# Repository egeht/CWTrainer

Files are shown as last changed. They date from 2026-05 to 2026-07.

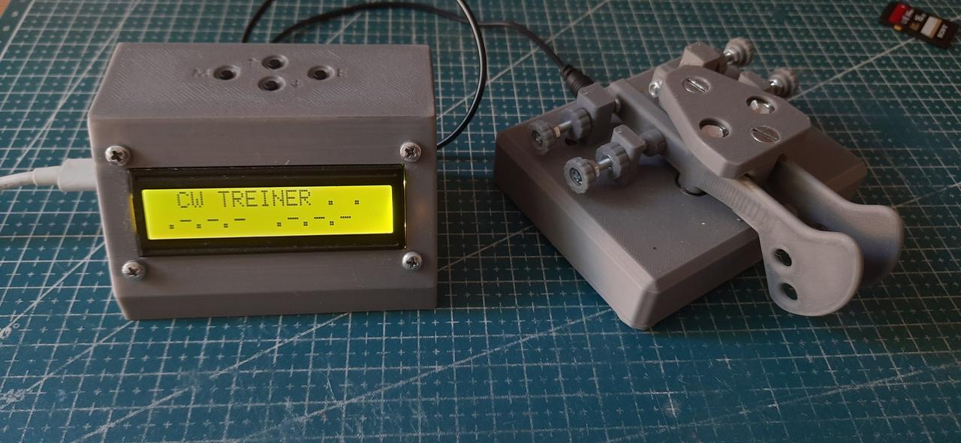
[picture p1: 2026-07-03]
docs/CWTrainer4.jpg

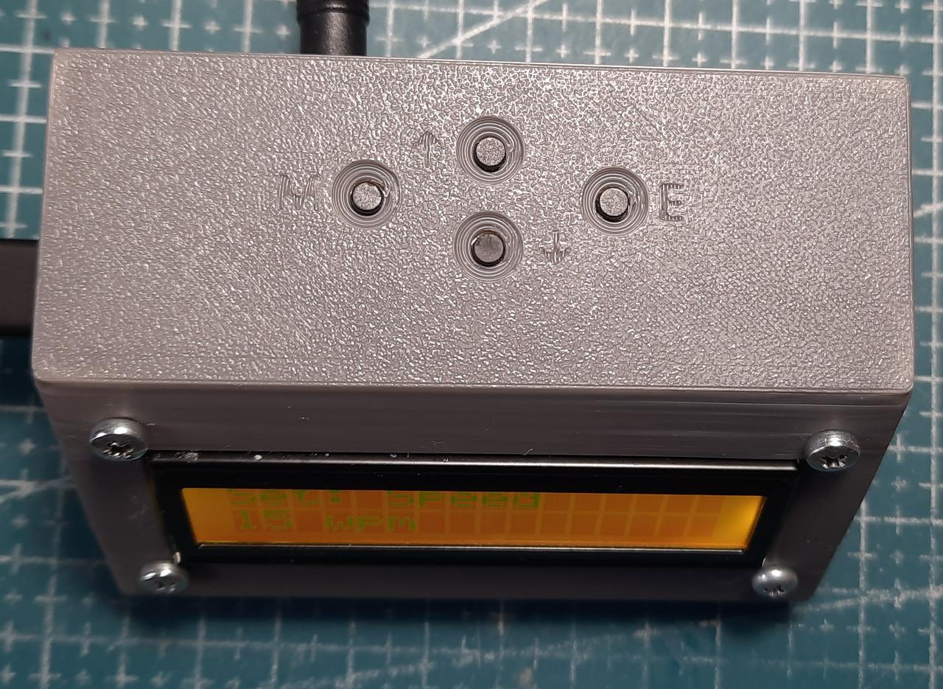
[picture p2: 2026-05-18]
docs/CWTrainer2.jpg

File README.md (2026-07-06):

# CWTrainer

Arduino nano CW electronic key/trainer

I needed an electronic CW key to learn Morse code (for practicing transmission). I came across an old key project from a radio amateur with the call sign PA3HCM (https://www.pa3hcm.nl/?p=1010). I used it as a basis. In the process, I modified the program so much that nothing remained of the original. :-)

The circuit diagram is almost unchanged (there's not much to change), I just replaced the board with an Arduino nano. To output sound to a speaker or headphones, I added a PAM8403 amplifier and a volume control. Just in case, I connected it to a transceiver, but I don't know why. If desired, you can plug a 3.5mm jack with an LED soldered onto it and see the light signals. I added four buttons to control the key setup menu. I also designed the enclosure.

What it can do:
- Works in iambic modes A and B.
- Works with a classic straight key.
When working with an iambic key, it displays the transmitted dots/dashes (on the bottom line) and the transmitted character (on the top line). This allows you to monitor the transmission.

The following parameters are configurable and stored in non-volatile memory:
- speed in WPM
- dash duration
- pause duration between signals
- pause duration between characters
- pause duration between words
All durations are entered in dot durations.

A printed circuit board (PCB) with a connector for the Arduino and a board with an audio amplifier and a volume control resistor is mounted on the bottom of the case (bottom step). The LCD1602 screen, a PCB with buttons, three connectors, and a speaker are mounted on the top of the case (top step).

I won't give any details on the components and layout, as everyone will have to use what they have on hand for this project.

This isn't a full-fledged simulator; it doesn't give you any tasks. And it doesn't check whether you've typed the right thing. It only shows what you've entered. But that's all I needed. :-)

You can see an example of it here - https://youtube.com/shorts/XV8_UpXhKHY?feature=share

# CWTrainer

Arduino nano CW электронный ключ/тренажер
 
Мне понадобился электронный CW ключ для изучения азбуки Морзе (для тренировки передачи). На глаза попался старый проект ключа от радиолюбителя с позывным PA3HCM (https://www.pa3hcm.nl/?p=1010). Взял его за основу. в процессе доработал программу так, что от оригинала ничего не осталось. :-)

Схема почти не поменялась (там и менять-то особенно не чего), только заменил платку на Arduino nano. Что бы можно было выводить звук на динамик или наушники добавил УНЧ на PAM8403 и регулятор громкости. На всякий случай сделал вывод на трансивер, не знаю зачем. При желании можно в него воткнуть джек 3.5 с припаянным светодиодом и видеть световые сигналы. Добавил четыре кнопки для управления меню настройки ключа. Нарисовал корпус.

Что умеет:
- Работает в ямбических режимах А и Б.
- Работает с классическим прямым ключом.
При работе с ямбическим ключом выводит на экран переданные точки/тире (в нижней строке) и переданный знак (в верхней строке). Таким образом можно контролировать передачу.

Настраивается и сохраняется в энергонезависимой памяти:
- скорость в WPM
- длительность тире
- длительность паузы между сигналами
- длительность паузы между символами
- длительность паузы между словами
Все длительности вводятся в длительностях точки.

На нижней части корпуса (bottom.step) крепится печатная (монтажная) плата с разъемом для Ардуино и платка с УНЧ и резистором регулятора громкости. На верхней части корпуса (top.step) экран LCD1602, печатная платка с кнопками, три разъема и динамик.

Не даю подробности комплектации и компоновки, потому что каждый будет делать исходя из того что у него есть под рукой для этого проекта.

Это не полноценный тренажер, он не дает вам ни каких заданий. И ни как не проверяет то ли вы набрали. Он только показывает что вы передали. Но мне только это и нужно было. :-)

Пример работы можно посмотреть здесь - https://youtube.com/shorts/XV8_UpXhKHY?feature=share

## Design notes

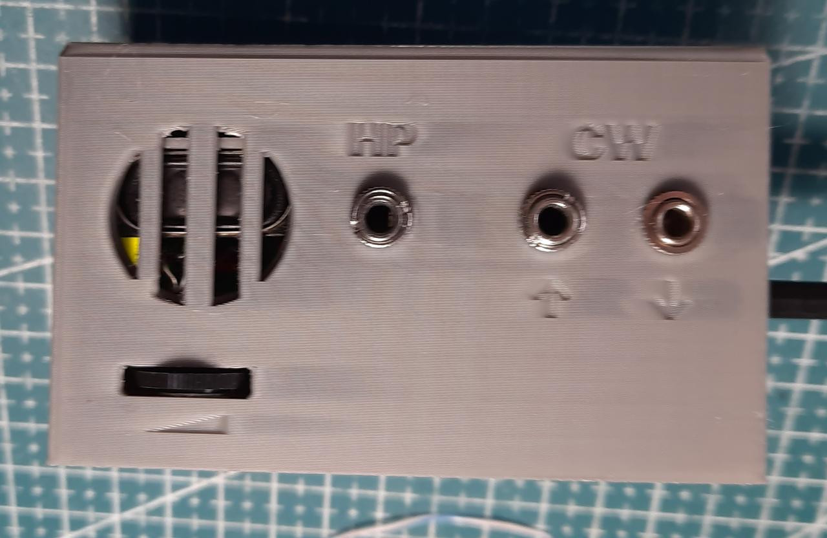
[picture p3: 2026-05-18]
docs/CWTrainer1.jpg

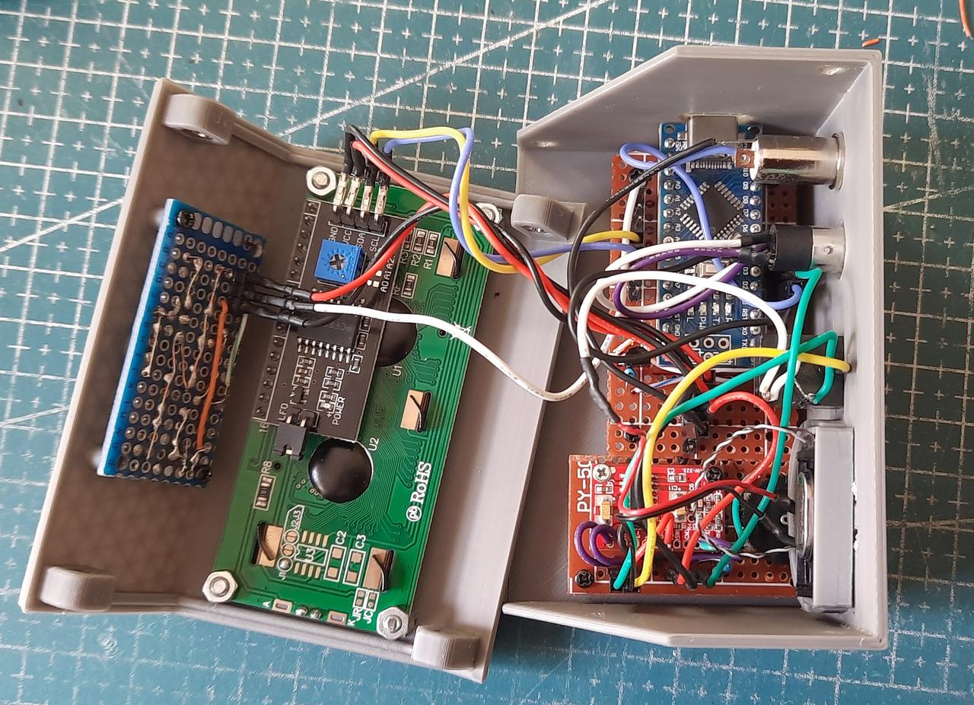
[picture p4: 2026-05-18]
docs/CWTrainer3.jpg

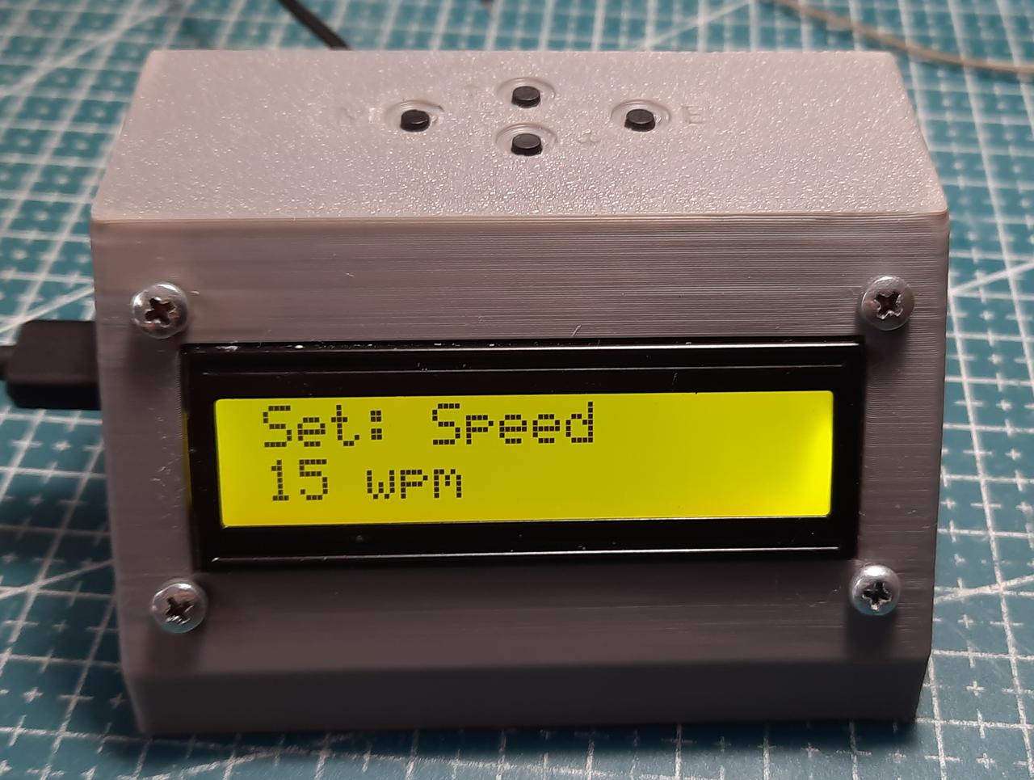
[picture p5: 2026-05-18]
docs/CWTrainer.jpg

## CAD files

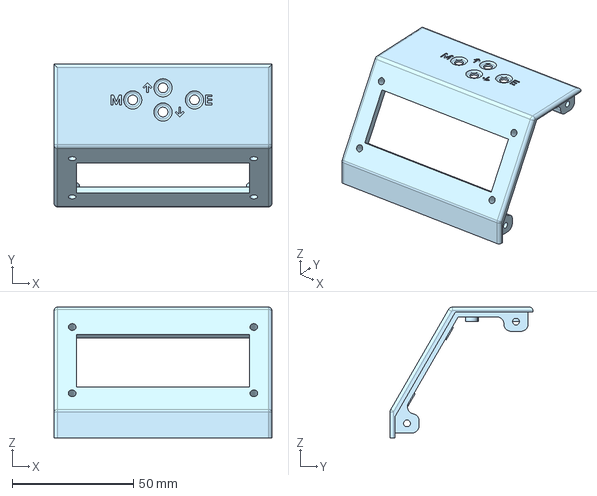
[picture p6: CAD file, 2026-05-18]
3d_models/top.step
90.0 x 59.0 x 54.0 mm

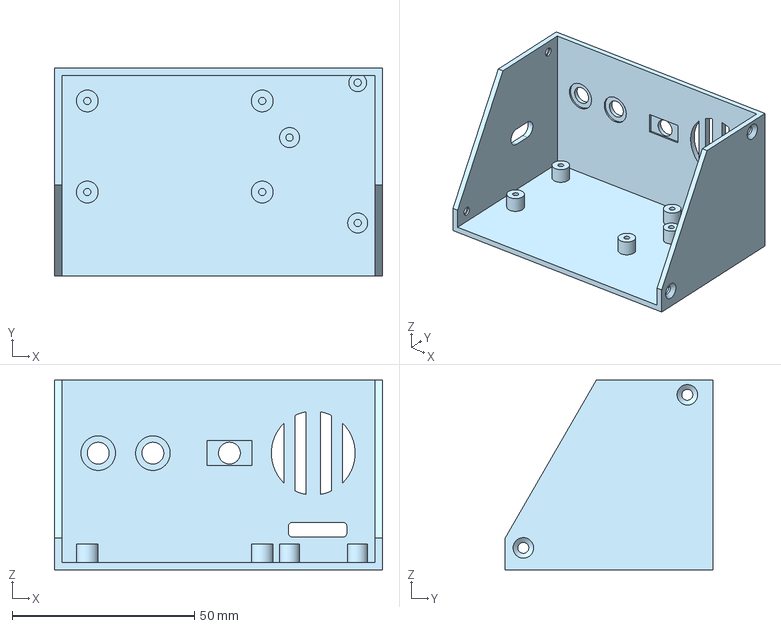
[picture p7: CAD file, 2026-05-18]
3d_models/bottom.step
90.0 x 57.0 x 52.0 mm

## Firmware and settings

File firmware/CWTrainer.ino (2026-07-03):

// CWTrainer
//
// by egeht exRA9MLF
// ver. 202600703
#define VER "1.00"
// 0.8 - замена обработки дребезга на бибоиотеку\
// 0.81 - реализация ямбик режима, вынов всего в функции
// 0.83 - как-то заработала, но похоже есть ошибки связанные с временем нажатия клавиш
// 0,84 - оставляем один опрос клавиш на цикл, реагируем только на устойчивые состояния, а не на события.
// 0.85 - замедлил опрос до один в 1 миллисекунду, почистил от старья. Работает в режиме ямбик А
// 0,86 - реализация режимов моде А и моде Б
// 0.87 - реализация режимов моде А и моде Б (отлажен)
// 0.88 - добавлен приямой ключ
// 0.89 - обработка нажатия кнопок управления меню
// 0.90 - сохранение настроек в eprom
// 0.91 - настройка программы
// 0.92 - RC1
// 0.93 - RC2 добавлне вывод на трнанссивер, этуляция обычного ключа (ключ нажат/не неажат)
// 0.94 - RC2
// 0,95 - изменил код ошибки и поменял местами точку и запятую
// 1.00 - изменил настройку промежутков междц словами (до 14) и шаг изменения на 0,5 RELISE

#include <SimpleButton.h>  // подавление дребезга
#include <LiquidCrystal_I2C.h>
#include <EEPROM.h>

LiquidCrystal_I2C lcd(0x27, 16, 2);  // адрес, столбцов, строк

bool IfDebug = false;  // true - включить отладку
// bool IfDebug = true;  // true - включить отладку
// bool IfDebug1 = false;
// bool IfDebug1 = true;

// Pin configuration
#define P_DOT 4       // D4 Connects to the dot lever of the paddle
#define P_DASH 5      // D5 Connects to the dash lever of the paddle
#define P_AUDIO 3     // D3 Speaker output
#define P_LCD_SDA A4  // LCD 1602 SDA
#define P_LCD_SCL A5  // LCD 1602 SCL
#define P_BTN A0      // Buttons
#define P_CW 6        // D output for transsiver

// microsecs in minute
#define US_PER_MIN 60000000

// 50 dot-long intervals in one "PARIS".
#define DOTS_PER_WORD 50

// логическое состояние ключа
#define DOT 1
#define DASH 2
#define NONE 3

// Режимы работы ямбик-ключа
#define IAMBIC_MODE_A 0  // классический режим A
#define IAMBIC_MODE_B 1  // режим B (с лишним элементом)
#define STRAIGHT_MODE 2  // вертикальный ключ

uint8_t iambicMode = IAMBIC_MODE_A;  // по умолчанию режим A
uint8_t pendingElement = NONE;       // для режима B: отложенный элемент после отпускания

float duration_dash = 3;        // длительность тире (в точках)
float pause_sign = 1;           // длительность паузы между сигналами (точка/тире)
float pause_letter = 3.0;       // длительность паузы между буквами
float pause_word = 7.0;         // длительность паузы между словами
uint16_t tone_frequency = 700;  // частота тона в герцах
uint8_t speed = 15;             // скорость передачи в словах в минуту

// длительности в единицах времени (ms - миллисекуды, us - микросекунды)
uint32_t stateTimerUs, duration_dot_us, duration_dash_us, pause_sign_us, pause_letter_us, pause_word_us;

uint8_t state;        // состояние автомата// состояния конечного автомата
#define state_Idle 1  // ничего не нажато, ждём paddle
#define state_Dot 3   // ключуем точка
#define state_Dash 4  // ключуем тире
#define state_Gap 5   // выдерживаем паузу после элемента

// уровень сигнала на пинах ключа
SimpleButton btnDot;   // true если точка нажата с подавлением дребезга
SimpleButton btnDash;  // true если тире нажата с подавлением дребезга

String morseLine = "";        // буфер точек/тире для показа на экране
String decodedLine = "";      // буфер расшифрованных букв для показа на экране
String morseBuffer = "";      // буфер одной буквы для рассшифровки
uint32_t silenceTimerUs = 0;  // таймер тишины с последнего элемента
bool decodingActive = false;  // флаг "идёт набор буквы"
bool wordSpaceAdded = false;  // флаг что слово закончено и пробел выведен

bool dotMemory = false;         // нажата точка
bool dashMemory = false;        // нажато тире
uint8_t currentElement = NONE;  // что сейчас звучит или только что звучало: DOT/DASH/NONE

bool dotIsPressed = false;  // устойчивое состояние: true - нажата, false - отпущена
bool dashIsPressed = false;
bool isToneOn;  // в режиме прямого ключа сигнал звучит

uint16_t BtnValue = 0;  // Состояние покоя кнопок

// Переменные меню
#define MENU_TIMEOUT 30000  // 30 секунд таймаут
#define MENU_OFF 0          // обычная работа ключа
#define MENU_SELECT 1       // выбор параметра (UP/DOWN перебираем параметры)
#define MENU_EDIT 2         // редактирование выбранного параметра (UP/DOWN меняем значение)
uint8_t menuState = 0;      // 0 - выкл, 1 - выбор, 2 - редактирование
uint8_t menuItem = 0;       // текущий пункт меню (0..6)
uint32_t menuTimer = 0;     // таймер для авто-выхода
bool menuNeedSave = false;  // флаг, что нужно сохранить настройки

// Названия пунктов меню (до 7 пунктов)
const char* menuItems[] = {
  "Speed", "Freq", "Dash", "Sign", "Letter", "Word", "Mode"
};
const uint8_t MENU_ITEMS_COUNT = 7;

// переменные которые нужно нестраивать и запоминать после изменения
// uint8_t iambicMode = IAMBIC_MODE_A;  // по умолчанию режим A
// float duration_dash = 3;        // длительность тире (в точках)
// float pause_sign = 1;           // длительность паузы между сигналами (точка/тире)
// float pause_letter = 3.0;       // длительность паузы между буквами
// float pause_word = 7.0;         // длительность паузы между словами
// uint16_t tone_frequency = 700;  // частота тока в герцах
// uint8_t speed = 15;             // скорость передачи в словах в минуту
// EEPROM адреса для хранения настроек
#define EE_IAMBIC_MODE 0
#define EE_DURATION_DASH 1
#define EE_PAUSE_SIGN 5  // float занимает 4 байта
#define EE_PAUSE_LETTER 9
#define EE_PAUSE_WORD 13
#define EE_TONE_FREQUENCY 17
#define EE_SPEED 19
#define EE_MAGIC_NUMBER 21  // для проверки, что EEPROM инициализирован

#define MAGIC_NUMBER_VAL 0xAB  // маркер, что настройки сохранены

// кнопки управления меню
#define BTN_NO 0
#define BTN_MENU 1
#define BTN_UP 2
#define BTN_DOWN 3
#define BTN_ENTER 4

//*****************************************************************************************
//******************************
// Initializing the Arduino
//******************************
//*****************************************************************************************
void setup() {

  pinMode(P_AUDIO, OUTPUT);
  pinMode(P_BTN, INPUT);
  pinMode(P_CW, OUTPUT);

  btnDot.begin(P_DOT);
  btnDash.begin(P_DASH);

  lcd.init();  // инициализация экрана
  lcd.noCursor();
  lcd.noBlink();
  lcd.backlight();  // включить подсветку

  // вывод заставки и сигнала

  lcd.setCursor(2, 0);  // столбец 1 строка 0
  lcd.print("(c) exRA9MLF");

  lcd.setCursor(0, 1);  // столбец 4 строка 1
  lcd.print("ver.");
  lcd.setCursor(5, 1);  // столбец 4 строка 1
  lcd.print(VER);

  // выдаем сигнал готовности VVV
  for (int i = 0; i <= 2; i++) {
    tone(P_AUDIO, tone_frequency, 80);
    delay(160);
    tone(P_AUDIO, tone_frequency, 80);
    delay(160);
    tone(P_AUDIO, tone_frequency, 80);
    delay(160);
    tone(P_AUDIO, tone_frequency, 240);
    delay(320);
  }

  delay(2000);
  lcd.clear();

  // Загружаем настройки из EEPROM
  loadSettingsFromEEPROM();

  updateSpeed();  // устанавливаем текущие значения параметров передачи

  state = state_Idle;  // автомат в начальное состояние
  stateTimerUs = 0;
  decodedLine = "";
  morseLine = "";
  morseBuffer = "";
  dotMemory = false;
  dashMemory = false;
  currentElement = NONE;
  dotIsPressed = false;
  dashIsPressed = false;
  isToneOn = false;
  silenceTimerUs = micros();  // чтобы сразу не началась передача

  if (IfDebug) {
    // Initializing serial port for debugging purposes
    Serial.begin(115200);  // 115200
    delay(10);
    Serial.println();
    Serial.println("Start");
    Serial.print("Dot=");
    Serial.print(duration_dot_us);  // длительность точки
    Serial.print(",Dash=");
    Serial.print(duration_dash_us);
    Serial.print(",Sign=");
    Serial.print(pause_sign_us);
    Serial.print(",Letter=");
    Serial.print(pause_letter_us);
    Serial.print(",Word=");
    Serial.print(pause_word_us);
  }
}

//***********************************************************************************
//****************************************
// Main routine
//****************************************
//***********************************************************************************

void loop() {
  uint32_t gapUs;       // текущая длительность паузы
  uint8_t nextElement;  // следующий элемент для передачи


  uint8_t newBtnValue = GetBtnValue();  // Получаем актуальное состояние кнопок с коррекцией дребезга

  if (BtnValue != newBtnValue) {  // Срабатывает только при ИЗМЕНЕНИИ состояния
    BtnValue = newBtnValue;       // запоминаем новое значение

    // Обработка меню (если активно)
    if (menuState != MENU_OFF) {
      handleMenu(BtnValue);
      if (menuState == MENU_OFF) return;  // если вышли из меню — пропускаем передачу
    }
    // Вход в меню по кнопке MENU (только если меню не активно)
    else if (BtnValue == BTN_MENU) {
      menuState = MENU_SELECT;
      menuItem = 0;
      menuTimer = millis();
      noTone(P_AUDIO);
      showMenu();
      return;  // пропускаем цикл передачи
    }
  }

  // Если меню активно — ничего больше не делаем
  if (menuState != MENU_OFF) return;


  readPaddles();  // читаем клавиши CW paddle

  // ОТЛАДКА: выводим состояние каждые 100 мс (чтобы не заспамить)
  static uint32_t lastDebug = 0;

  if (iambicMode == STRAIGHT_MODE) {
    // прямой колюч, просто пищим

    if (dotIsPressed) {
      // нажат прямой ключ
      digitalWrite(P_CW, HIGH);   // выдаем сигнал транссивер
      tone(P_AUDIO, tone_frequency); 
      isToneOn = true;
    } else {
      if (isToneOn) {
        digitalWrite(P_CW, LOW);
        noTone(P_AUDIO);
        isToneOn = false;
      }
    }
    return;
  }

  switch (state) {
    case state_Idle:
      // Проверка, выдержана ли пауза после последнего элемента
      if (currentElement != NONE && (micros() - silenceTimerUs < pause_sign_us)) {
        break;
      }

      nextElement = chooseNextElement();

      if (nextElement == DOT) {
        consumeElement(DOT);
        currentElement = DOT;
        stateTimerUs = micros();
        digitalWrite(P_CW, HIGH);       // выдаем сигнал на транссивер
        tone(P_AUDIO, tone_frequency);
        addMorse('.');
        state = state_Dot;
      } else if (nextElement == DASH) {
        consumeElement(DASH);
        currentElement = DASH;
        stateTimerUs = micros();
        digitalWrite(P_CW, HIGH);       // выдаем сигнал на транссивер        
        tone(P_AUDIO, tone_frequency);
        addMorse('-');
        state = state_Dash;
      }
      break;

    case state_Dot:
      if (micros() - stateTimerUs >= duration_dot_us) {
        noTone(P_AUDIO);
        digitalWrite(P_CW, LOW);       // глушим сигнал на транссивер
        silenceTimerUs = micros();
        state = state_Gap;
      }
      break;

    case state_Dash:
      if (micros() - stateTimerUs >= duration_dash_us) {
        noTone(P_AUDIO);
        digitalWrite(P_CW, LOW);       // глушим сигнал на транссивер
        silenceTimerUs = micros();
        state = state_Gap;
      }
      break;

    case state_Gap:
      gapUs = micros() - silenceTimerUs;
      // ... декодирование букв/слов (эту часть можно оставить без изменений) ...
      // Конец буквы
      if (gapUs >= pause_letter_us && decodingActive) {
        String decoded = decodeMorse(morseBuffer);
        addLetter(decoded);
        morseBuffer = "";
        decodingActive = false;
      }

      // Конец слова
      if (gapUs >= pause_word_us) {
        if (!wordSpaceAdded && decodedLine.length() > 0) {
          addLetter(" ");
          wordSpaceAdded = true;
        }
      }
      if (gapUs >= pause_sign_us) {
        nextElement = chooseNextElement();
        if (nextElement == DOT) {
          consumeElement(DOT);
          currentElement = DOT;
          stateTimerUs = micros();
          digitalWrite(P_CW, HIGH);       // выдаем сигнал на транссивер
          tone(P_AUDIO, tone_frequency);
          addMorse('.');
          state = state_Dot;
        } else if (nextElement == DASH) {
          consumeElement(DASH);
          currentElement = DASH;
          stateTimerUs = micros();
          digitalWrite(P_CW, HIGH);       // выдаем сигнал на транссивер
          tone(P_AUDIO, tone_frequency);
          addMorse('-');
          state = state_Dash;
        }
      }
      break;
  }
}


//*********************************
// функции
//*********************************

// расчет тайминга в микросекундах по скорости в wpm и коэффициентов длительности
void updateSpeed() {
  duration_dot_us = US_PER_MIN / (DOTS_PER_WORD * speed);  // длительность точки
  duration_dash_us = duration_dot_us * duration_dash;      // длительность тире
  pause_sign_us = duration_dot_us * pause_sign;            // длительность паузы между знаками
  pause_letter_us = duration_dot_us * pause_letter;        // длительность паузы между буквами
  pause_word_us = duration_dot_us * pause_word;            // длительность паузы между словами
}

// Функция чтения paddle
// обновляет подтверждённые состояния двух лепестков
void readPaddles() {
  // Обновляем стабильное состояние каждой клавиши
  // isHeld() == true  -> кнопка нажата и стабильна
  // isIdle()  == true -> кнопка отпущена и стабильна
  // Эти два метода взаимно исключают друг друга (если не между состояниями)

  static uint32_t lastRead = 0;
  if (micros() - lastRead < 1000) return;  // читаем не чаще 1 раза в 1 мс
  lastRead = micros();

  bool oldDotPressed = dotIsPressed;
  bool oldDashPressed = dashIsPressed;

  dotIsPressed = btnDot.isHeld();
  dashIsPressed = btnDash.isHeld();

  // Если нужна дополнительная защита: если isIdle() истинно, то точно не нажата
  if (btnDot.isIdle()) dotIsPressed = false;
  if (btnDash.isIdle()) dashIsPressed = false;

  // Однократные события нажатия (фронт)
  bool dotJustPressed = btnDot.debounce();
  bool dashJustPressed = btnDash.debounce();

  // События отпускания (фронт вверх)
  bool dotJustReleased = btnDot.onRelease();
  bool dashJustReleased = btnDash.onRelease();

  // Теперь эти события можно использовать для установки флагов памяти
  if (dotJustPressed) dotMemory = true;
  if (dashJustPressed) dashMemory = true;

  // === ЛОГИКА ДЛЯ РЕЖИМА B ===
  if (iambicMode == IAMBIC_MODE_B) {
    static bool bothWerePressed = false;
    static uint32_t bothLostTime = 0;

    // Если обе нажаты - запоминаем
    if (dotIsPressed && dashIsPressed) {
      bothWerePressed = true;
      bothLostTime = 0;
    }

    // Если обе отпущены и до этого были нажаты
    if (bothWerePressed && !dotIsPressed && !dashIsPressed) {
      if (currentElement != NONE) {
        pendingElement = (currentElement == DOT) ? DASH : DOT;
      }
      bothWerePressed = false;
    }

    // Таймаут: если прошло 100 мс, а вторая кнопка так и не нажата - сбрасываем
    if (bothWerePressed && !(dotIsPressed && dashIsPressed)) {
      if (bothLostTime == 0) bothLostTime = millis();
      if (millis() - bothLostTime > 100) {
        bothWerePressed = false;
        bothLostTime = 0;
      }
    }
  }
}

// Функция выбора следующего элемента
// Если обе памяти установлены, следующий элемент — противоположный только что сыгранному.
// Это и даёт нормальное iambic-чередование.
uint8_t chooseNextElement() {
  // Для режима B: отложенный элемент имеет высший приоритет
  if (iambicMode == IAMBIC_MODE_B && pendingElement != NONE) {
    uint8_t result = pendingElement;
    pendingElement = NONE;
    return result;
  }

  uint8_t result = NONE;

  // 1. Удерживается только точка
  if (dotIsPressed && !dashIsPressed) {
    result = DOT;
  }
  // 2. Удерживается только тире
  else if (!dotIsPressed && dashIsPressed) {
    result = DASH;
  }
  // 3. Удерживаются обе (squeeze) -> чередование
  else if (dotIsPressed && dashIsPressed) {
    if (currentElement == DOT) result = DASH;
    else if (currentElement == DASH) result = DOT;
    else result = DOT;
  }
  // 4. Обе отпущены, но что-то осталось в памяти
  else if (dotMemory && dashMemory) {
    if (currentElement == DOT) result = DASH;
    else if (currentElement == DASH) result = DOT;
    else result = DOT;
  } else if (dotMemory) result = DOT;
  else if (dashMemory) result = DASH;

  return result;
}

// Функция сброса использованной памяти
// Если запускаем точку, очищаем только dotMemory; если тире — только dashMemory.
// Вторая память может остаться и дать следующий элемент.
void consumeElement(uint8_t el) {
  if (el == DOT) {
    dotMemory = false;
  } else if (el == DASH) {
    dashMemory = false;
  }

  // Для режима B: если начали отложенный элемент, сбрасываем
  if (iambicMode == IAMBIC_MODE_B && pendingElement == el) {
    pendingElement = NONE;
  }
}

void addMorse(char dotOrDash) {
  //полученный знак выводим на экран и добавляем в буфер для последющей расшифровки.
  decodingActive = true;
  morseLine += dotOrDash;
  morseBuffer += dotOrDash;
  wordSpaceAdded = false;
  // если строка заполнена, сдвигаем влево
  if (morseLine.length() > 16) morseLine = morseLine.substring(1);  // сдвиг
}

void addLetter(String symbol) {
  // добавляем символ в буквенную строку и выводим на экран
  decodedLine += symbol;
  if (decodedLine.length() > 16) decodedLine = decodedLine.substring(decodedLine.length() - 16);
  lcd.setCursor(0, 0);
  lcd.print(decodedLine + "                ");
  morseLine += ' ';
  if (morseLine.length() > 16) morseLine = morseLine.substring(1);  // сдвиг
  lcd.setCursor(0, 1);
  lcd.print(morseLine + "                ");  // новая + пробелы
}

// декодируем набранный символ
String decodeMorse(String morseCode) {
  if (morseCode == ".-") return "A";
  if (morseCode == "-...") return "B";
  if (morseCode == "-.-.") return "C";
  if (morseCode == "-..") return "D";
  if (morseCode == ".") return "E";
  if (morseCode == "..-.") return "F";
  if (morseCode == "--.") return "G";
  if (morseCode == "....") return "H";
  if (morseCode == "..") return "I";
  if (morseCode == ".---") return "J";
  if (morseCode == "-.-") return "K";  // общее приглашение к передаче
  if (morseCode == ".-..") return "L";
  if (morseCode == "--") return "M";
  if (morseCode == "-.") return "N";
  if (morseCode == "---") return "O";
  if (morseCode == ".--.") return "P";
  if (morseCode == "--.-") return "Q";
  if (morseCode == ".-.") return "R";
  if (morseCode == "...") return "S";
  if (morseCode == "-") return "T";
  if (morseCode == "..-") return "U";
  if (morseCode == "...-") return "V";
  if (morseCode == ".--") return "W";
  if (morseCode == "-..-") return "X";
  if (morseCode == "-.--") return "Y";
  if (morseCode == "--..") return "Z";

  if (morseCode == "-----") return "0";
  if (morseCode == ".----") return "1";
  if (morseCode == "..---") return "2";
  if (morseCode == "...--") return "3";
  if (morseCode == "....-") return "4";
  if (morseCode == ".....") return "5";
  if (morseCode == "-....") return "6";
  if (morseCode == "--...") return "7";
  if (morseCode == "---..") return "8";
  if (morseCode == "----.") return "9";

  if (morseCode == ".-.-.-") return ".";
  if (morseCode == "--..--") return ",";
  if (morseCode == "-.-.--") return "!";
  if (morseCode == "..---..") return "?";
  if (morseCode == "-..-.") return "/";

  if (morseCode == ".-.-.") return "AR";
  if (morseCode == "...-.-") return "SK";  // конец работы
  if (morseCode == "-...-") return "=";    // BT -
  if (morseCode == "-.--.") return "KN";
  if (morseCode == "-.-.-") return "KA";
  if (morseCode == "...-...-...-") return "VVV";  // начало передачи

  return "Err";
}

uint8_t GetBtnValue() {  // Функция устраняющая дребезг
  static int count;
  static uint8_t oldBtn;  // Переменная для хранения предыдущего значения состояния кнопок
  static uint8_t innerBtn;
  static uint8_t actualBtn;
  uint16_t actualBtnValue = analogRead(P_BTN);  // Получаем актуальное состояние

  // настроить значения здесь под ваши резисторы в блоке кнопок
  if (actualBtnValue <= 128) {
    actualBtn = BTN_NO;
  } else if (actualBtnValue <= 384) {
    actualBtn = BTN_MENU;
  } else if (actualBtnValue <= 640) {
    actualBtn = BTN_UP;
  } else if (actualBtnValue <= 896) {
    actualBtn = BTN_DOWN;
  } else {
    actualBtn = BTN_ENTER;
  }

  if (innerBtn != actualBtn) {  // Пришло значение отличное от предыдущего
    count = 0;                  // Все обнуляем и начинаем считать заново
    innerBtn = actualBtn;       // Запоминаем новое значение
  } else {
    count += 1;  // Увеличиваем счетчик
  }

  if ((count >= 10) && (actualBtn != oldBtn)) {  // Счетчик преодолел барьер, можно иницировать смену состояний
    oldBtn = actualBtn;                          // Присваиваем новое значение
  }
  return oldBtn;
}

//*****************************************************************************************
// Функции работы с EEPROM
//*****************************************************************************************

// Сохранение всех настроек в EEPROM
void saveSettingsToEEPROM() {
  EEPROM.put(EE_IAMBIC_MODE, iambicMode);
  EEPROM.put(EE_DURATION_DASH, duration_dash);
  EEPROM.put(EE_PAUSE_SIGN, pause_sign);
  EEPROM.put(EE_PAUSE_LETTER, pause_letter);
  EEPROM.put(EE_PAUSE_WORD, pause_word);
  EEPROM.put(EE_TONE_FREQUENCY, tone_frequency);
  EEPROM.put(EE_SPEED, speed);
  EEPROM.put(EE_MAGIC_NUMBER, MAGIC_NUMBER_VAL);

  if (IfDebug) {
    Serial.println("Settings saved to EEPROM");
  }
}
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

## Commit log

2026-05-18 Create CWTrainer.kicad_sch
    добавил в проект схему
    [CWTrainer.kicad_sch]
2026-05-18 Update README.md
    добавил описание
2026-05-18 добавил фото и файлы моделей
    добавил фото и файлы моделей
    [bottom.step, top.step]
2026-06-21 RC2
    подключен вывод на транссивер
    [CWTrainer.kicad_sch]
2026-06-26 замени символ ошибки набора на "Err"
2026-07-03 0.95 RC2
    [CWTrainer.kicad_sch]
